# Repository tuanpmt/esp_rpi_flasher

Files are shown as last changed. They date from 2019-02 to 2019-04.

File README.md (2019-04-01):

# ESP32 RPI FLASHER

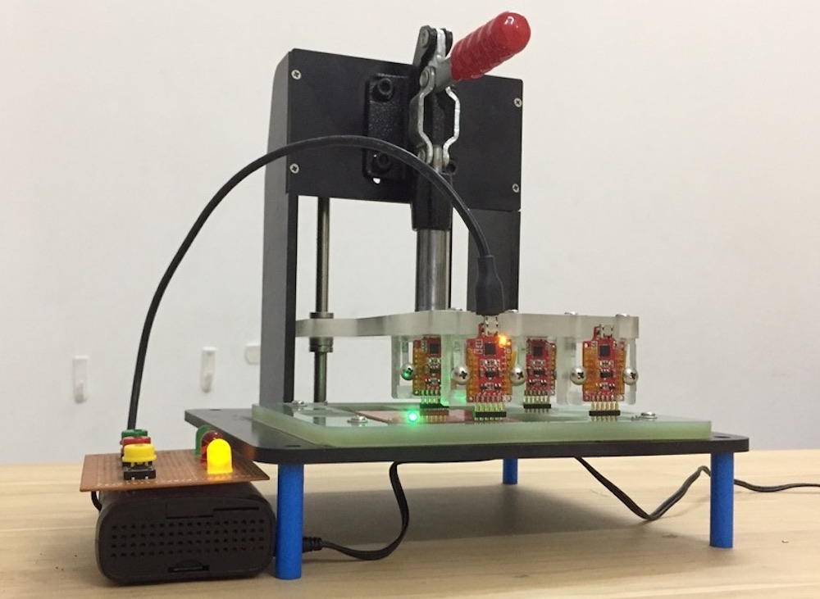
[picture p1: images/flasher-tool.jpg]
flasher tool example

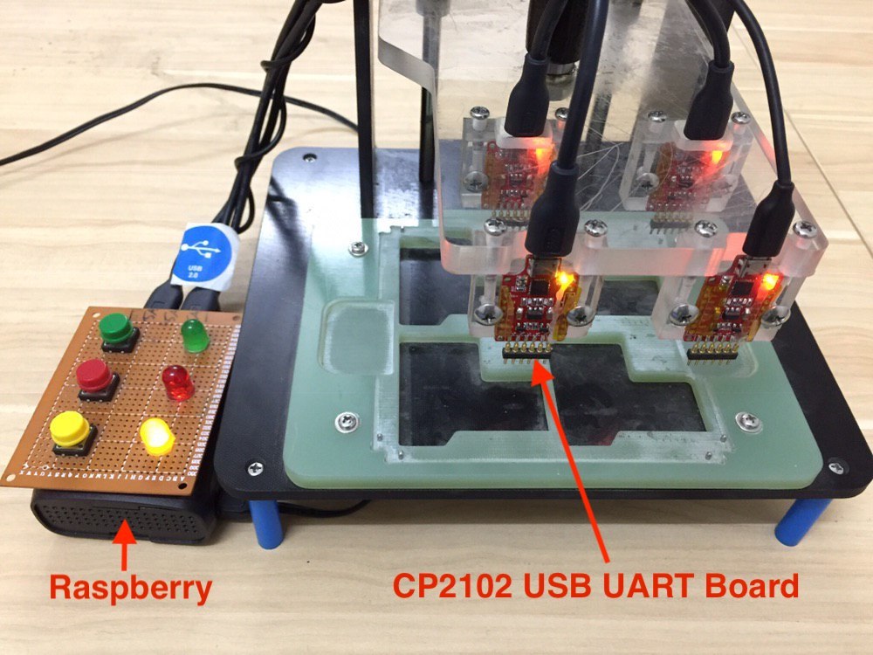
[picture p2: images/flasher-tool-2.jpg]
flasher tool example


Language: [Việt Nam](./README.vi.md)

## Introduction

When mass-producing ESP32's products we need to have the tool to load the program for the product as quickly as possible. We have several ways to optimize and speed up loading binary firmware for ESP32 as follows:
- Flash multiple products at the same time
- Reduce the binary size
- Speed up the UART baudrate
- Automate loading steps (automatically into bootloader mode ...)

ESP RPI FLASHER is a set of ESP32 multi-board load support tools at the same time including:
- High-speed USB-UART CP2102 board, supporting baudrate speed up to 2Mbps
- The program running on Raspberry Pi can use multiple CP2102 at the same time

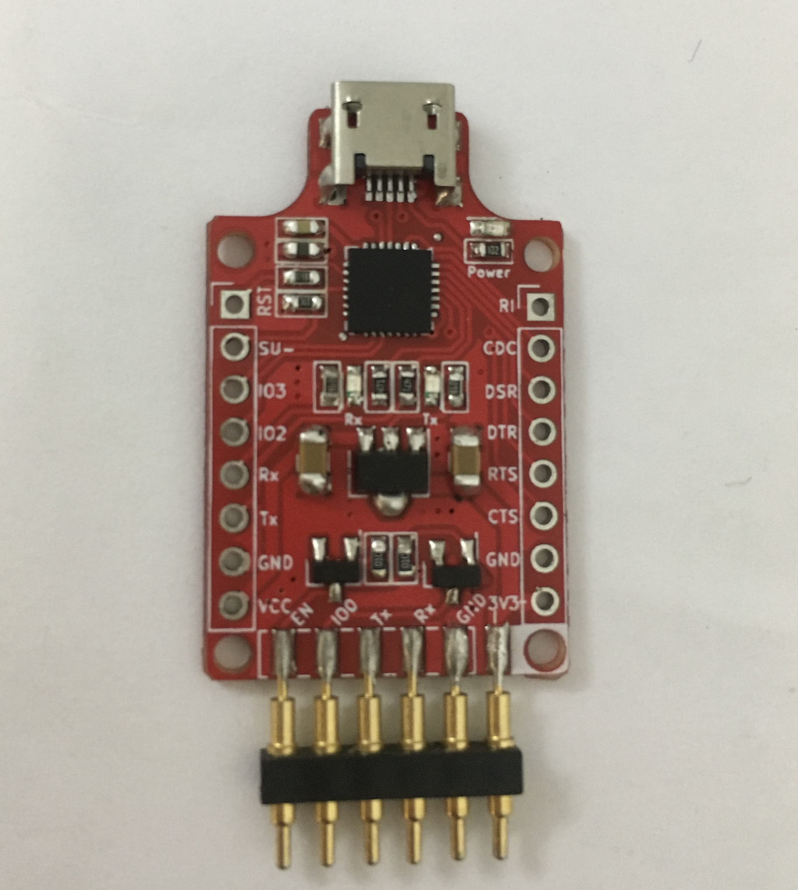
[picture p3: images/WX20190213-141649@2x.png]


The features of the program run on Raspberri Pi as follows:
- Automatically identify the CP2102 that is being connected (can plug multiple via USB port)
- Change firmware for ESP32 easily with configuration file
- Allow reflash failed boards.

## Prepare
* [Raspberry Pi 3 Model B/B+](https://www.raspberrypi.org)
* Thẻ nhớ 16GB
* [CP2102 USB UART board](./esp32_cp_programmer)
* Micro USB Cable, Button, LED, PCB prototype.

**Functianal button and LED**

|  | Function |
|:---:|:---:|
| Flash Button | Click to flash the program |
| Reflash Button | Click to re-flash the failed board |
| Reboot Button | Click to restart Raspberry |
| Flash LED | Report device loading program |
| Reflash LED | Report with loaded board failed |
| Ready LED | Raspberry are ready to be used |

## Steps

### Step 1: Connect device hardware

**Wire connections**

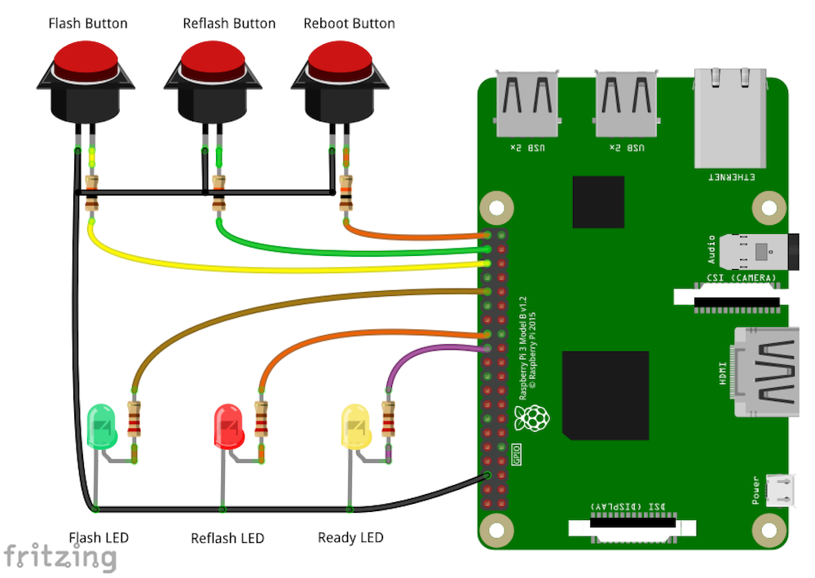
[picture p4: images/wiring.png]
Wiring


| | Raspberry Pin |
|:---:|:---:|
| Flash Button | 16 |
| Reflash Button | 20 |
| Reboot Button | 21 |
| Flash LED | 12 |
| Reflash LED | 7 |
| Ready LED | 8 |

The control circuit board after welding is fixed

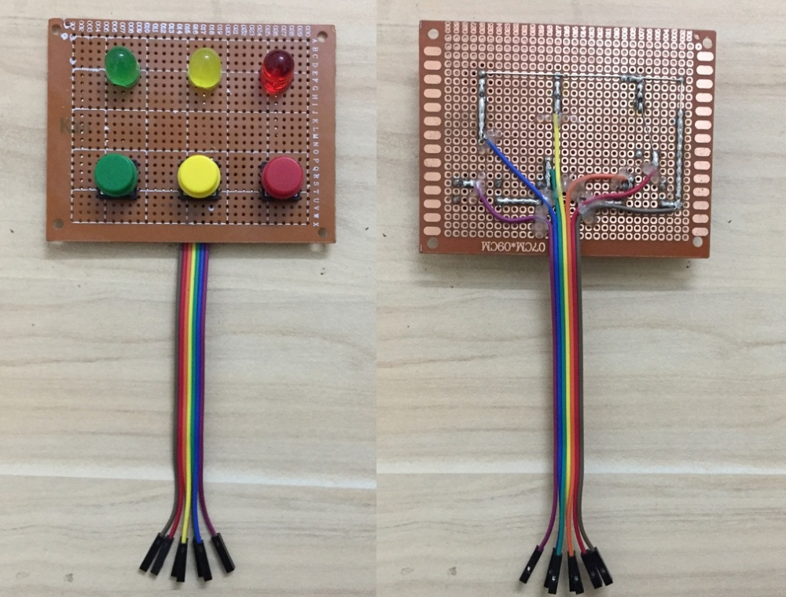
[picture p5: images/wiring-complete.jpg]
wiring complete


### Step 2: Installing Raspbian for raspberry
* Download the latest Raspbian version [here](https://www.raspberrypi.org/downloads/raspbian/).
* Extract the downloaded file (the file after extracting has `.img` extension).
* Insert a memory card, open the terminal and execute the `sudo fdisk -l` command
* Determine the disk name when inserting a memory card, usually /dev/mmcblk0.
* Continue to execute the commands:
     * `cd Downloads /`
     * `sudo dd bs = 4M if = 2017-07-05-raspbian-jessie-lite.img of = /dev/mmcblk0`
* Note: The `cd Downloads/` command is used to go to the directory containing the installation file.
* Once done, we have a memory card that can boot Raspbian.

**Ref:** [Cách cài đặt hệ điều hành raspbian cho raspberry.](https://www.raspberrypi.org/documentation/installation/installing-images/)

**Setting Wifi and SSH to Raspberry PI**
* Remove the memory card and plug it back into the computer. At this time, The Linux/Ubuntu OS will mount 2 partitions, `boot` partition and `rootfs` partition.
* using `rootfs`, and open **/etc/wpa-supplicant/wpa-supplicant.conf** in this directory:
* Edit that file with this conntent:
```
ctrl_interface=DIR=/var/run/wpa_supplicant GROUP=netdev
update_config=1
network={
  ssid="your ssid"
  psk="your pass"
}
```

* Since November 2016, Raspberry has locked SSH when starting. To unlock SSH, create an `ssh` file (note: this file does not have an extension) in the boot partition of SD Card.
* Insert the memory card into RPI and wait for it to start in about 1 minute.
* Find the IP address of raspberry by logging in to the configuration page of WiFi Modem (for example: http://192.168.1.1). Almost all modems will display the DHCP Client list, find whichever host name is raspberrypi, get that IP, for example 192.168.1.12. In addition, some IP scanning software support such as [Angry IP Scanner](https://angryip.org/download/#mac).
* Open terminal up, ssh to raspberry's IP address: `ssh pi @ 192.168.1.12` and type the password:` raspberry` (Note the computer needs to use the same network with raspberry).
* So finished installing Raspbian for Raspberry Pi.

### Step 3: Install script

* Open the terminal, ssh by `ssh pi@192.168.1.12` with password: `raspberry`.
* Clone project: `git clone --recursive https://github.com/tuanpmt/esp_rpi_flasher.git`

**Note:** By default, the project needs to be saved in the **/home/pi** directory, if you want to save the script to another location, refer to [Configuring directory path](#Configuration-picture-path-letter-item).

* Install python and provide the firmware to the correct directory (using the `firmware_examples`):

```
sudo pip install -r requirements.txt
``` 

### Step 4: Set up auto-run script when raspberry starts
* After installing the raspberry script, check the current directory path with the command: `$PWD` (the default path is /home/pi/esp_rpi_flasher)
* Type `sudo nano /home/pi/.bashrc` to edit the **.Bashrc** file
* Add the following content to the last line of the file **.Bashrc**

```
echo Running at boot 
sudo /usr/bin/python3 /home/pi/esp_rpi_flasher/flasher.py &
```

With: `/home/pi/esp_rpi_flasher/flasher.py` is the default path of the project, if the script is saved in another location
* Nhấn **Ctrol** + **x** để save và reboot raspberry bằng lệnh `sudo reboot`.

Check out some more ways to run scripts when starting raspbian [here](https://www.dexterindustries.com/howto/run-a-program-on-your-raspberry-pi-at-startup/)

## Notes

The basic settings and firmware will be saved in the `/boot/firmware` path as follows:

```
boot
├──firmware
    ├──config.ini
    ├──encrypted
        ├──app-encrypted.bin
        ├──bootloader-reflash-digest-encrypted.bin
        ├──ota_data_initial-encrypted.bin
        ├──partitions-encrypted.bin
        ├──flash_encryption_key_1.0.0.alpha.4.bin
        ├──secure-bootloader-key-256.bin
    ├──normal
        ├──app.bin
        ├──bootloader.bin
        ├──ota_data_initial.bin
        ├──partitions.bin
```

Inside:
* **config.ini**: File stores configurations such as: LED pins, buttons and firmware paths, ...
* **encrypted**: The directory contains the encrypted firmware (used when loading programs that can boot boot and flash encryption).
* **normal**: The folder contains unencrypted firmware (used when loading regular programs).

### Secure boot and flash encryption
By default the script will load the program in the usual way (without secure boot and flash encryption). Enter the `/boot/firmware/` directory and open the `config.ini` file and edit `isEncrypt = True` to load the program to secure boot and flash encryption.

### Configure directory path
By default the script needs to be saved under the path `/home/pi` however, if you want to save the script in another directory you need to edit:
* When completing step 1, step 2, step 3, in the `/boot/firmware/` directory open the **config.ini** file and change the path of **projectPath**
* In step 4: Automatically run the script when starting raspbian, need to change the path to the **flasher.py** file

### Raspberry configuration and Button of Raspberry

LED and push button have been declared by default as Step 1 if you want to change the LED connector pins and Button with raspberry, proceed to the `/boot/firmware/` folder open the ** config.ini file ** and change the LED and Button pins accordingly.

## Video

esp-rpi-flasher (https://youtu.be/gd818KGObi0 "ESP RPI FLASHER")

## Ref

* [Raspberry Pi3 model B/B+](https://www.raspberrypi.org/products/raspberry-pi-3-model-b-plus/)
* [Install Raspbian for raspberry](https://www.raspberrypi.org/documentation/installation/installing-images/)
* [Five Ways To Run a Program On Raspberry Pi At Startup](https://www.dexterindustries.com/howto/run-a-program-on-your-raspberry-pi-at-startup/)
* [Wiring Fritzing](images/wiring.fzz)

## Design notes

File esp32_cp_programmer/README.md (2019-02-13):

# ESP32 Progammer

## Features

ESP32 Progammer
- Size: 22x30.5 mm.
- Intergrate micro USB.
- Input Voltage: 5v (Vusb).
- Open hardware with CC-BY-SA license.
- Design with KiCad.

## Hardware

### Schematics

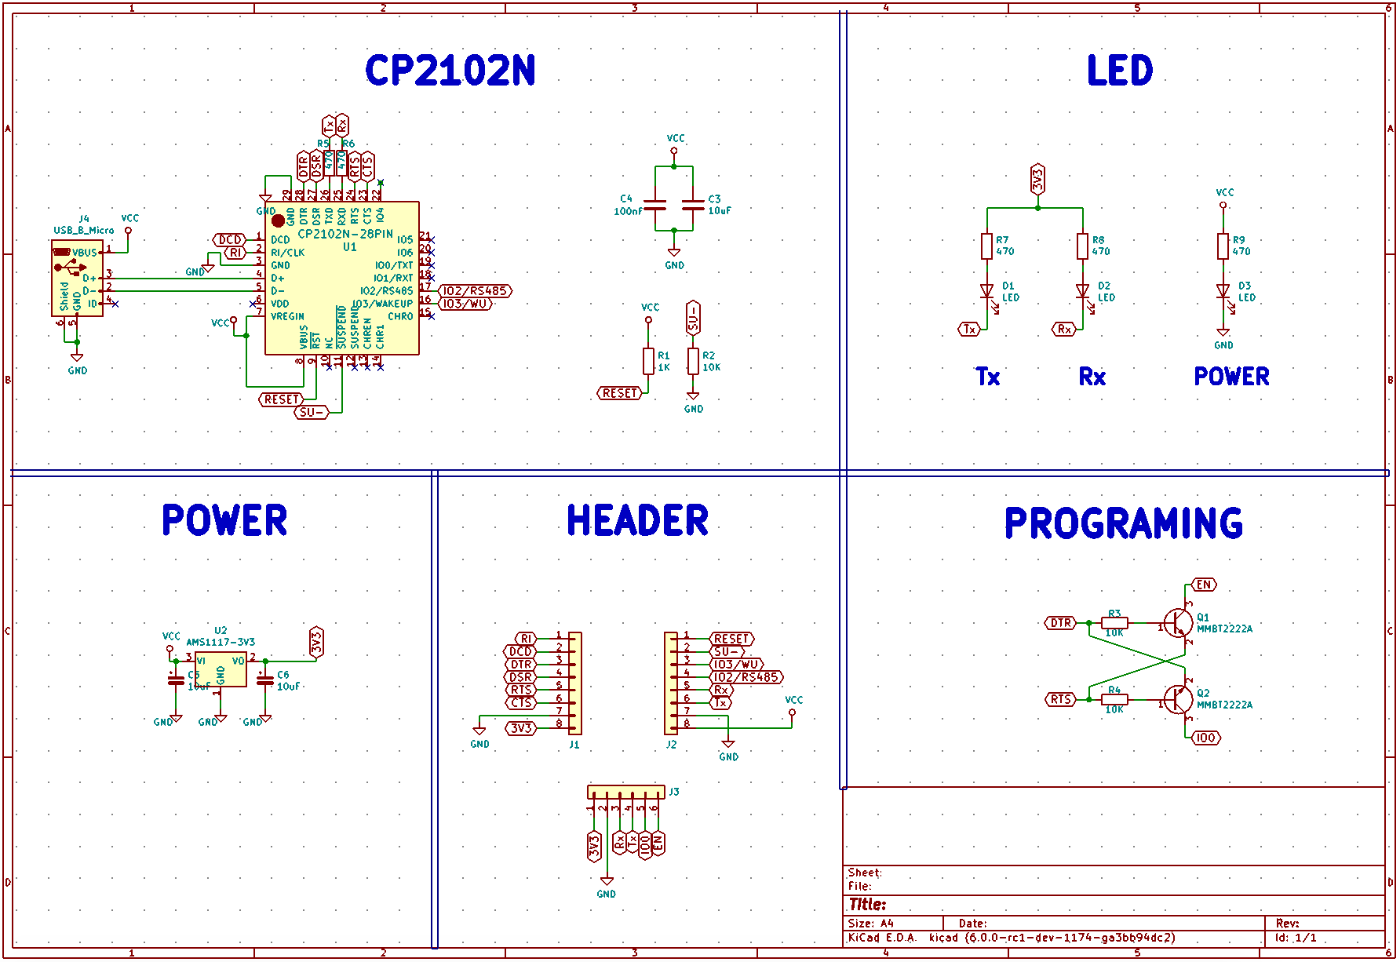
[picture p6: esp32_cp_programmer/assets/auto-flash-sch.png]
auto flash ESP32 Schematic


### PCB Layout

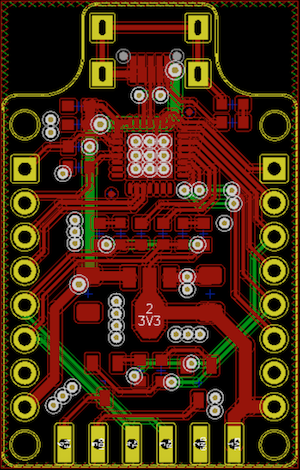
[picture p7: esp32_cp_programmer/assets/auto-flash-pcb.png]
auto flash ESP32 PCB


### 3D

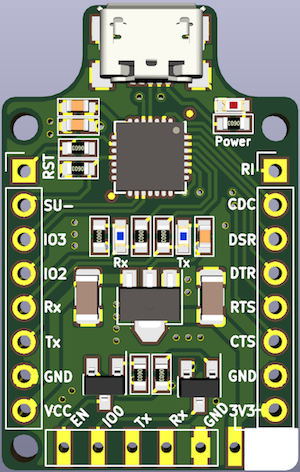
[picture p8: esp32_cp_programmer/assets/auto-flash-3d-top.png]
auto flash ESP32 3D


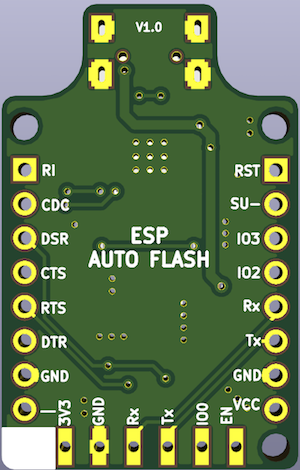
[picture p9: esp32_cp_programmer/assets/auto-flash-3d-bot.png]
auto flash ESP32 3D


### Pinout 

### Fritzing part 

### Gerber

* [Gerber 1 board](./assets/auto-flash-esp32-22x36,5mm.zip)
* [Gerber panel 8 board](./assets/auto-flash-panel-8-board-94x71mm.zip)

### BOM 
| Component | Description | Part | References | Value | Footprint | Quantity Per PCB | link |
|---|---|---|---|---|---|---|---|
| 1 | Unpolarized capacitor | C	| C1 C2 C3 | 100nF | C_0603 | 3 | |	
| 2 | Unpolarized capacitor | C	| C4 C5	| 4.7uF	| C_0603 | 2 | |	
| 3 | LED generic | LED	| D1 D2 D3 | LED | LED_0603 | 3 | |	
| 4 | Generic connector, single row, 01x06 | Conn_01x06	| J3 | Conn_01x06 | Pin_Header_Straight_1x06_Pitch2.54mm | 1 | [link](https://item.taobao.com/item.htm?id=524060094118) |	
| 5 | Generic connector, single row, 01x08 | Conn_01x08	| J1 J2 | Conn_01x08 | Pin_Header_Straight_1x08_Pitch2.54mm | 2 | |	
| 6 | USB Micro Type B connector | USB_B_Micro	| J4 | USB_B_Micro | MicroUSB-B	| 1 | |	
| 7 | Transistor NPN (general) | Q_NPN_BEC | Q1 Q2 | Q_NPN_BEC | SOT-23_standar | 2 | |	
| 8 | Resistor | R | R2 R3 R4 | 10K | R_0603 | 3 | |	
| 9 | Resistor | R | R1	| 1K | R_0603 | 1 | |
| 10 | Resistor | R | R7 R8 R9 | 220 | R_0603 | 3 |  |	
| 11 | Resistor | R | R5 R6 | 470 | R_0603 | 2 | |
| 12 | | CP2102N | U1 | CP2102N | cp2102 | 1 | [link](https://item.taobao.com/item.htm?id=563461942639) |	

### Remark

This project was in development phase - we will remove this remark after release

# License



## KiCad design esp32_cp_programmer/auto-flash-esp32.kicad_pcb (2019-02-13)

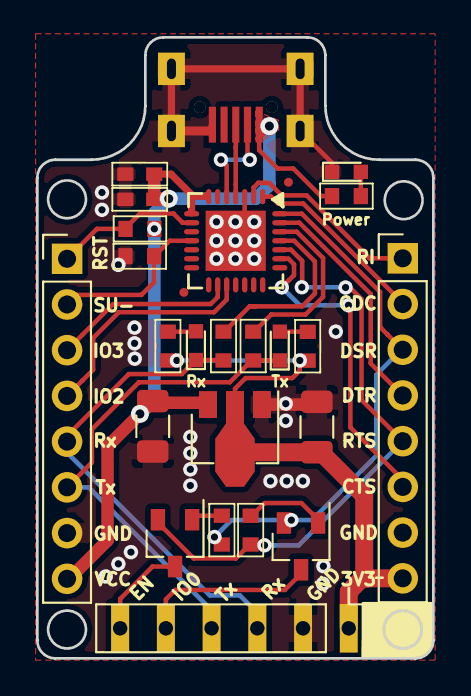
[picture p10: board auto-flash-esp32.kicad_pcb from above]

Board: 2 copper layers, 22.0 x 34.5 mm, 24 parts (0 on the bottom side), 26 nets.

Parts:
C3: 0.1uF; C_0603
C4: 4.7uF; C_0603
C5, C6: C_Small; C_1206_3216Metric
D1, D2, D3: LED; LED_0603
J1, J2: Conn_01x08; Pin_Header_Straight_1x08_Pitch2.54mm
J3: Conn_01x06; Pin_Header_Straight_1x06_Pitch2.54mm
J4: USB_B_Micro; MicroUSB-B
Q1, Q2: Q_NPN_BEC; SOT-23_standar
R1: 1K; R_0603
R2, R3, R4: 10K; R_0603
R5, R6: 470; R_0603
R7, R8, R9: 220; R_0603
U1: CP2102N-28PIN; QFN-28-1EP_5x5mm_Pitch0.5mm
U2: AMS1117-3V3; SOT-89-3

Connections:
3V3: C6.1, J1.8, J3.1, R7.2, R8.2, U2.2
CTS: J1.6, U1.23
DCD: J1.2, U1.1
DSR: J1.4, U1.27
DTR: J1.3, Q2.2, R3.2, U1.28
EN: J3.6, Q1.3
GND: C3.2, C4.2, C5.2, C6.2, D3.1, J1.7, J2.7, J3.2, J4.5, R2.2, U1.3, U1.29, U2.1
IO0: J3.5, Q2.3
IO2/RS485: J2.4, U1.17
IO3/WU: J2.3, U1.16
unnamed: D1.2, R7.1
unnamed: D2.2, R8.1
unnamed: D3.2, R9.1
unnamed: J4.2, U1.5
unnamed: J4.3, U1.4
unnamed: Q1.1, R3.1
unnamed: Q2.1, R4.1
unnamed: R5.1, U1.26
unnamed: R6.1, U1.25
RESET: J2.1, R1.2, U1.9
RI: J1.1, U1.2
RTS: J1.5, Q1.2, R4.2, U1.24
Rx: D2.1, J2.5, J3.3, R6.2
SU-: J2.2, R2.1, U1.11
Tx: D1.1, J2.6, J3.4, R5.2
VCC: C3.1, C4.1, C5.1, J2.8, J4.1, R1.1, R9.2, U1.7, U1.8, U2.3

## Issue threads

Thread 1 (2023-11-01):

how many board at the same time?

processor83, 2023-11-01:
thank you for this script it look promising,  just wanted to make sur i understand i  can connect many esp32 to my rpi vuia usb press program and  wait for green light it flash them all and rewrite failed ones ?

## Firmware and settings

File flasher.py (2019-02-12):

#! /usr/bin/env python
import argparse
import configparser
import glob
import os
import os.path
import RPi.GPIO as GPIO
import serial
import subprocess
import sys
import threading
from time import sleep

PYTHON=sys.executable

configFilePath = ("/boot/code/config.ini")
config = configparser.ConfigParser()
config.read(configFilePath)

projectPath = config.get('DEFAULT', 'projectPath')
isEncrypt = config.get('DEFAULT', 'isEncrypt')
if isEncrypt == 'True':
    bootloaderPath = config.get('ENCRYPT', 'bootloaderPath')
    partitionsPath = config.get('ENCRYPT', 'partitionsPath')
    otaDataPath = config.get('ENCRYPT', 'otaDataPath')
    appDataPath = config.get('ENCRYPT', 'appDataPath')
    secureBootloaderKeyPath = config.get('ENCRYPT', 'secureBootloaderKeyPath')
    flashEcryptionKeyPath = config.get('ENCRYPT', 'flashEcryptionKeyPath')
else:
    bootloaderPath = config.get('DEFAULT', 'bootloaderPath')
    partitionsPath = config.get('DEFAULT', 'partitionsPath')
    otaDataPath = config.get('DEFAULT', 'otaDataPath')
    appDataPath = config.get('DEFAULT', 'appDataPath')
    secureBootloaderKeyPath = config.get('DEFAULT', 'secureBootloaderKeyPath')
    flashEcryptionKeyPath = config.get('DEFAULT', 'flashEcryptionKeyPath')

flashButton = int(config.get('DEFAULT', 'flashButton'))
reFlashButton = int(config.get('DEFAULT', 'reFlashButton'))
rebootButton = int(config.get('DEFAULT', 'rebootButton'))
flashingLED = int(config.get('DEFAULT', 'flashingLED'))
reFlashLED = int(config.get('DEFAULT', 'reFlashLED'))
readyLED = int(config.get('DEFAULT', 'readyLED'))
# config LED and button
GPIO.setmode(GPIO.BCM)
GPIO.setwarnings(False)
GPIO.setup(flashButton, GPIO.IN, pull_up_down=GPIO.PUD_UP) 
GPIO.setup(reFlashButton, GPIO.IN, pull_up_down=GPIO.PUD_UP)
GPIO.setup(rebootButton, GPIO.IN, pull_up_down=GPIO.PUD_UP)  
GPIO.setup(flashingLED, GPIO.OUT, initial=GPIO.LOW)
GPIO.setup(reFlashLED, GPIO.OUT, initial=GPIO.LOW)
GPIO.setup(readyLED, GPIO.OUT, initial=GPIO.LOW)

reFlashPorts = []  # list reflash port
flashFlag = False
reFlashFlag = False
rebootFlag = False

def _get_args(type, esptool_path, port, baud):
    if type == "burn_secure_key":
        result = [ PYTHON, esptool_path ]
        result += [ "--port", port ]
        result += [ "--do-not-confirm" ]
        result += [ "--before", "default_reset" ]
        result += [ "burn_key" ]
        result += [ "secure_boot", secureBootloaderKeyPath ]
        return result
    elif type == "burn_flash_encryption_key":
        result = [ PYTHON, esptool_path ]
        result += [ "--port", port ]
        result += [ "--do-not-confirm" ]
        result += [ "--before", "default_reset" ]
        result += [ "burn_key" ]
        result += [ "flash_encryption", flashEcryptionKeyPath ]
        return result
    elif type == "burn_efuse_cnt":
        result = [ PYTHON, esptool_path ]
        result += [ "--port", port ]
        result += [ "--do-not-confirm" ]
        result += [ "--before", "default_reset" ]
        result += [ "burn_efuse" ]
        result += [ "FLASH_CRYPT_CNT", "1" ]
        return result
    elif type == "burn_efuse_config":
        result = [ PYTHON, esptool_path ]
        result += [ "--port", port ]
        result += [ "--do-not-confirm" ]
        result += [ "--before", "default_reset" ]
        result += [ "burn_efuse" ]
        result += [ "FLASH_CRYPT_CONFIG", "0xf" ]
        return result
    elif type == "flash":
        result = [ PYTHON, esptool_path ]
        result += [ "--chip", "esp32" ]
        result += [ "--port", port ]
        result += [ "--baud", str(baud) ]
        result += [ "--before", "default_reset" ]
        result += [ "--after", "hard_reset" ]
        result += [ "write_flash", "-z" ]
        result += [ "--flash_mode", "dio" ]
        result += [ "--flash_freq", "40m" ]
        result += [ "--flash_size", "detect" ]
        result += [ "0x10000", appDataPath ]
        result += [ "0x8000", partitionsPath ]
        result += [ "0x0", bootloaderPath ]
        result += [ "0xe000", otaDataPath ]
        return result
    elif type == "erase_flash":
        result = [ PYTHON, esptool_path ]
        result += [ "--port", port ]
        result += [ "erase_flash" ]
        return result
    else:
        return 0

# get current USB ports
def _get_ports():
    if sys.platform.startswith('linux') or sys.platform.startswith('cygwin'):
        ports = glob.glob('/dev/tty[Uu]*')
    elif sys.platform.startswith('darwin'):
        ports = glob.glob('/dev/tty.U*')
    else:
        raise EnvironmentError('Unsupported platform')
    result = []
    for port in ports:
        try:
            s = serial.Serial(port)
            s.close()
            result.append(port)
        except (OSError, serial.SerialException):
            pass
    return result
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

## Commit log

2019-02-13 Rename folder, remove pcb
    add English
    Change youtube url
    add pcb
    rm cp program
    Add hardware
    [auto-flash-esp32.kicad_pcb, auto-flash-esp32.sch]
2019-02-13 change pcb project name

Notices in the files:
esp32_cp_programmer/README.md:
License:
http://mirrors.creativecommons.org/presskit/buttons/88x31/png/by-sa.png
